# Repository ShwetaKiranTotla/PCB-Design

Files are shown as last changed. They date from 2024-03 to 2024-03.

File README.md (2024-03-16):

# PCB-Design
I had attended a course "Design with KiCAD" (By Wissam Botros) on Udemy from which I learnt the know-hows of PCB Design. This repository contains source files for the open-source projects I have designed along with other finished PCBs I have built.

#
3D model of a Motor Controller board for DC and stepper motors based on the L298 driver module. It can drive two 3-30V DC motors and is capable of 2A continuous current per channel. 
Motor_Controller_3d_board1
 
#
Power Supply module for an Electric Vehicle  
Power_Supply_3d
#
Servo Control Card for an Aerospace application that independently controls six servo motor driven by PWM signals from micrcontroller and receives analog feedback.
Servo_Control_Card 3d
#
Schematic of the L298 Motor Controller Board.
Motor_Controller_Schematic_1

PCB Design of the Motor Controller board
motor_controller_pcb1

Back view of the Motor Controller PCB  
Motor_Controller_3d_board2

#
A three phase level shifter PCB to drive a three phase six signal load from PWM signals generated by micrcontroller.
level_shifter_1

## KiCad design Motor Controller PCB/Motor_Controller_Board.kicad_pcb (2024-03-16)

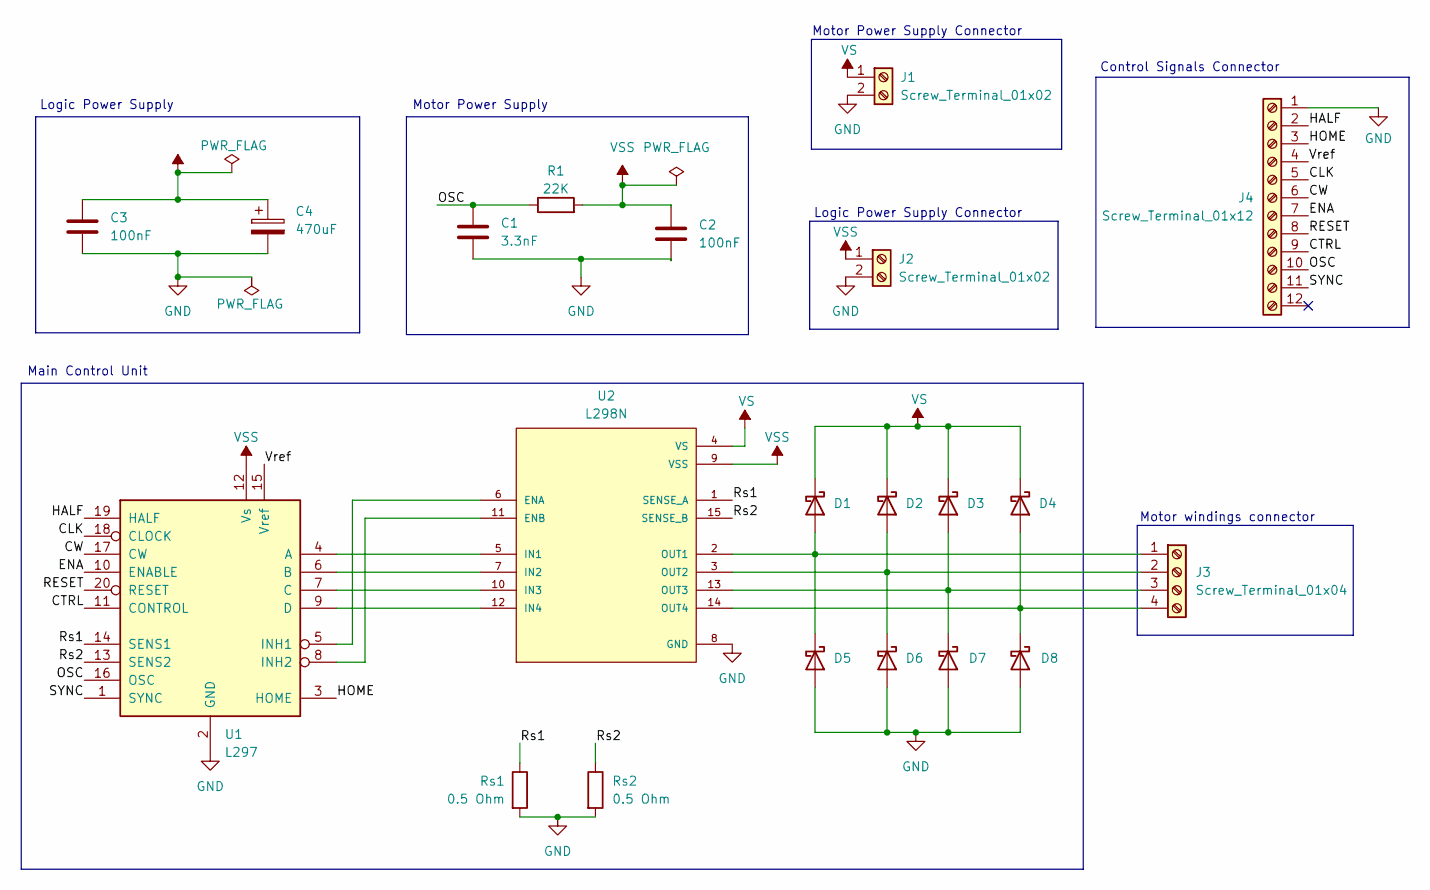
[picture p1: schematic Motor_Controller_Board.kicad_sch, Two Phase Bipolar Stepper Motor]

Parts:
C1: 3.3nF; C_Rect_L10.0mm_W3.0mm_P7.50mm_FKS3_FKP3
C2, C3: 100nF; C_Rect_L7.5mm_W6.5mm_P5.00mm
C4: 470uF; CP_Radial_D13.0mm_P5.00mm
D1, D2, D3, D4, D5, D6, D7, D8: D_Schottky; D_DO-27_P15.24mm_Horizontal
J1, J2: Screw_Terminal_01x02; TerminalBlock_Phoenix_MKDS-1,5-2-5.08_1x02_P5.08mm_Horizont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
J3: Screw_Terminal_01x04; TerminalBlock_Phoenix_MKDS-1,5-4_1x04_P5.00mm_Horizontal
J4: Screw_Terminal_01x12; TerminalBlock_Phoenix_MKDS-1,5-12_1x12_P5.00mm_Horizontal
R1: 22K; R_Axial_DIN0922_L20.0mm_D9.0mm_P25.40mm_Horizontal
Rs1, Rs2: 0.5 Ohm; R_Axial_DIN0414_L11.9mm_D4.5mm_P15.24mm_Horizontal
U1: L297; DIP-20_W7.62mm_LongPads
U2: L298N; TO127P2020X500X2100-15; DigiKey_Part_Number 497-1395-5-ND

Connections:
/CLK: J4.5, U1.18 (CLOCK)
/CTRL: J4.9, U1.11 (CONTROL)
/CW: J4.6, U1.17 (CW)
/ENA: J4.7, U1.10 (ENABLE)
/HALF: J4.2, U1.19 (HALF)
/HOME: J4.3, U1.3 (HOME)
/OSC: C1.1, J4.10, R1.1, U1.16 (OSC)
/RESET: J4.8, U1.20 (RESET)
/Rs1: Rs1.1, U1.14 (SENS1), U2.1 (SENSE_A)
/Rs2: Rs2.1, U1.13 (SENS2), U2.15 (SENSE_B)
/SYNC: J4.11, U1.1 (SYNC)
/Vref: J4.4, U1.15 (Vref)
GND: C1.2, C2.2, C3.2, C4.2, D5.2 (A), D6.2 (A), D7.2 (A), D8.2 (A), J1.2, J2.2, J4.1, Rs1.2, Rs2.2, U1.2 (GND), U2.8 (GND)
unnamed: D1.2 (A), D5.1 (K), J3.1, U2.2 (OUT1)
unnamed: D2.2 (A), D6.1 (K), J3.2, U2.3 (OUT2)
unnamed: D3.2 (A), D7.1 (K), J3.3, U2.13 (OUT3)
unnamed: D4.2 (A), D8.1 (K), J3.4, U2.14 (OUT4)
unnamed: U1.4 (A), U2.5 (IN1)
unnamed: U1.6 (B), U2.7 (IN2)
unnamed: U1.7 (C), U2.10 (IN3)
unnamed: U1.9 (D), U2.12 (IN4)
unnamed: U1.5 (INH1), U2.6 (ENA)
unnamed: U1.8 (INH2), U2.11 (ENB)
VS: C3.1, C4.1, D1.1 (K), D2.1 (K), D3.1 (K), D4.1 (K), J1.1, U2.4 (VS)
VSS: C2.1, J2.1, R1.2, U1.12 (Vs), U2.9 (VSS)

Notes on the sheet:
Logic Power Supply Connector
Main Control Unit
Motor Power Supply Connector
Logic Power Supply
Control Signals Connector
Motor windings connector
Motor Power Supply

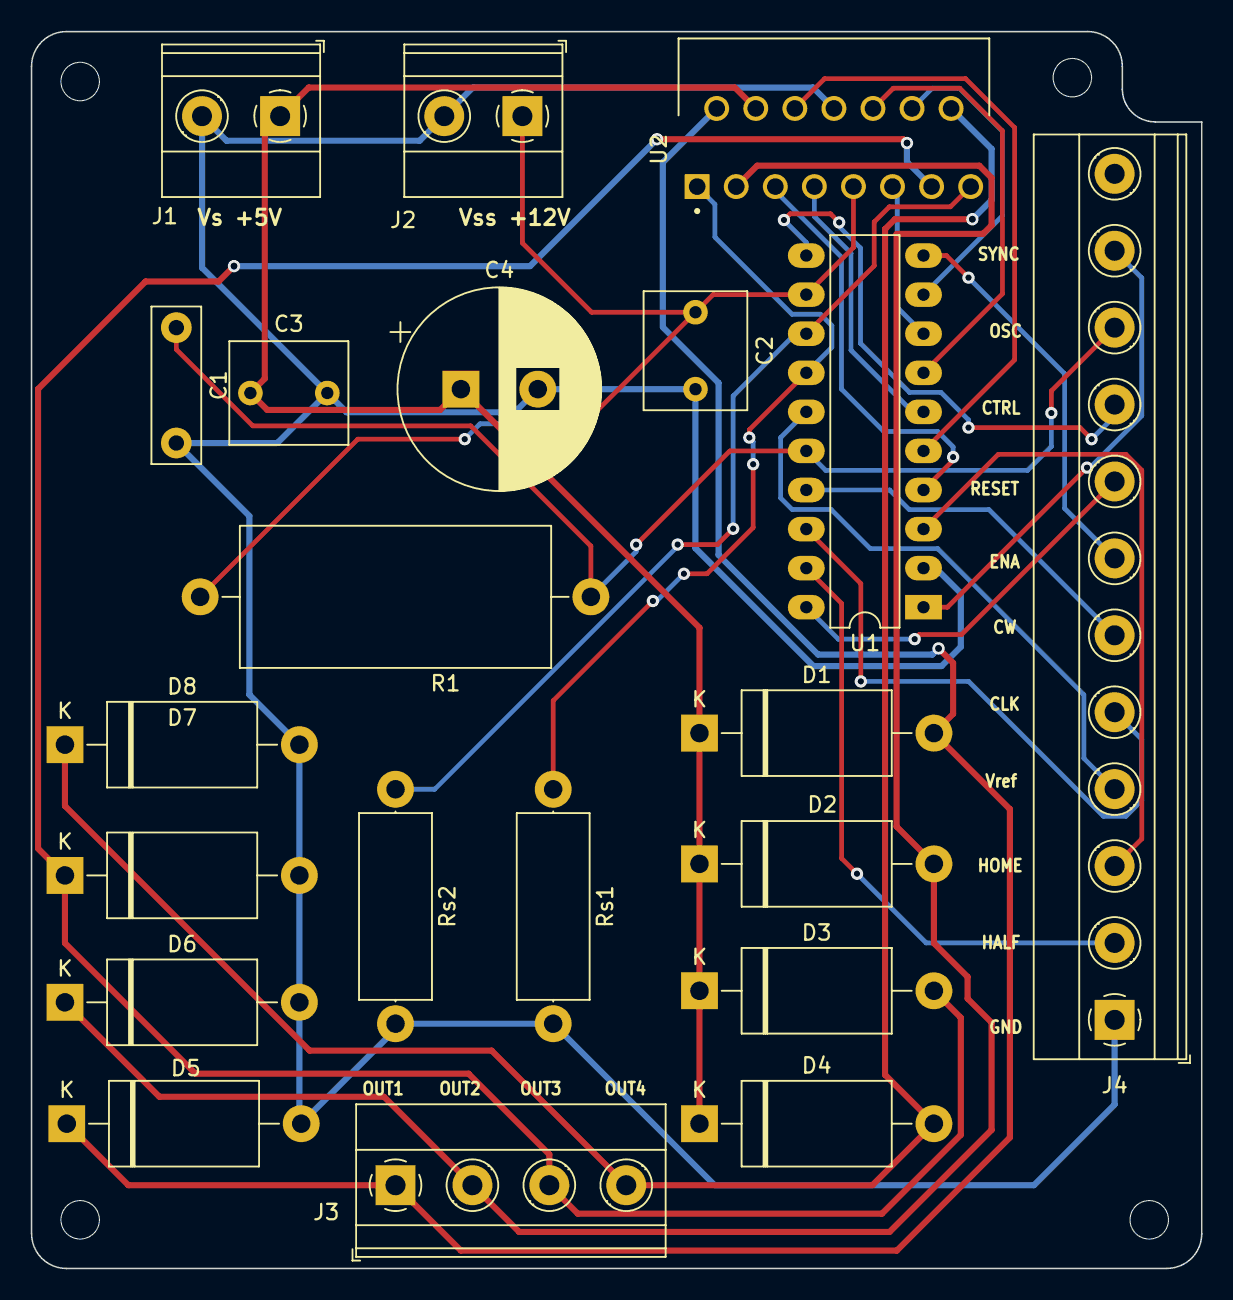
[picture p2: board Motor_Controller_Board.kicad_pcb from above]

Board: 2 copper layers, 76.1 x 80.4 mm, 21 parts (0 on the bottom side), 25 nets.

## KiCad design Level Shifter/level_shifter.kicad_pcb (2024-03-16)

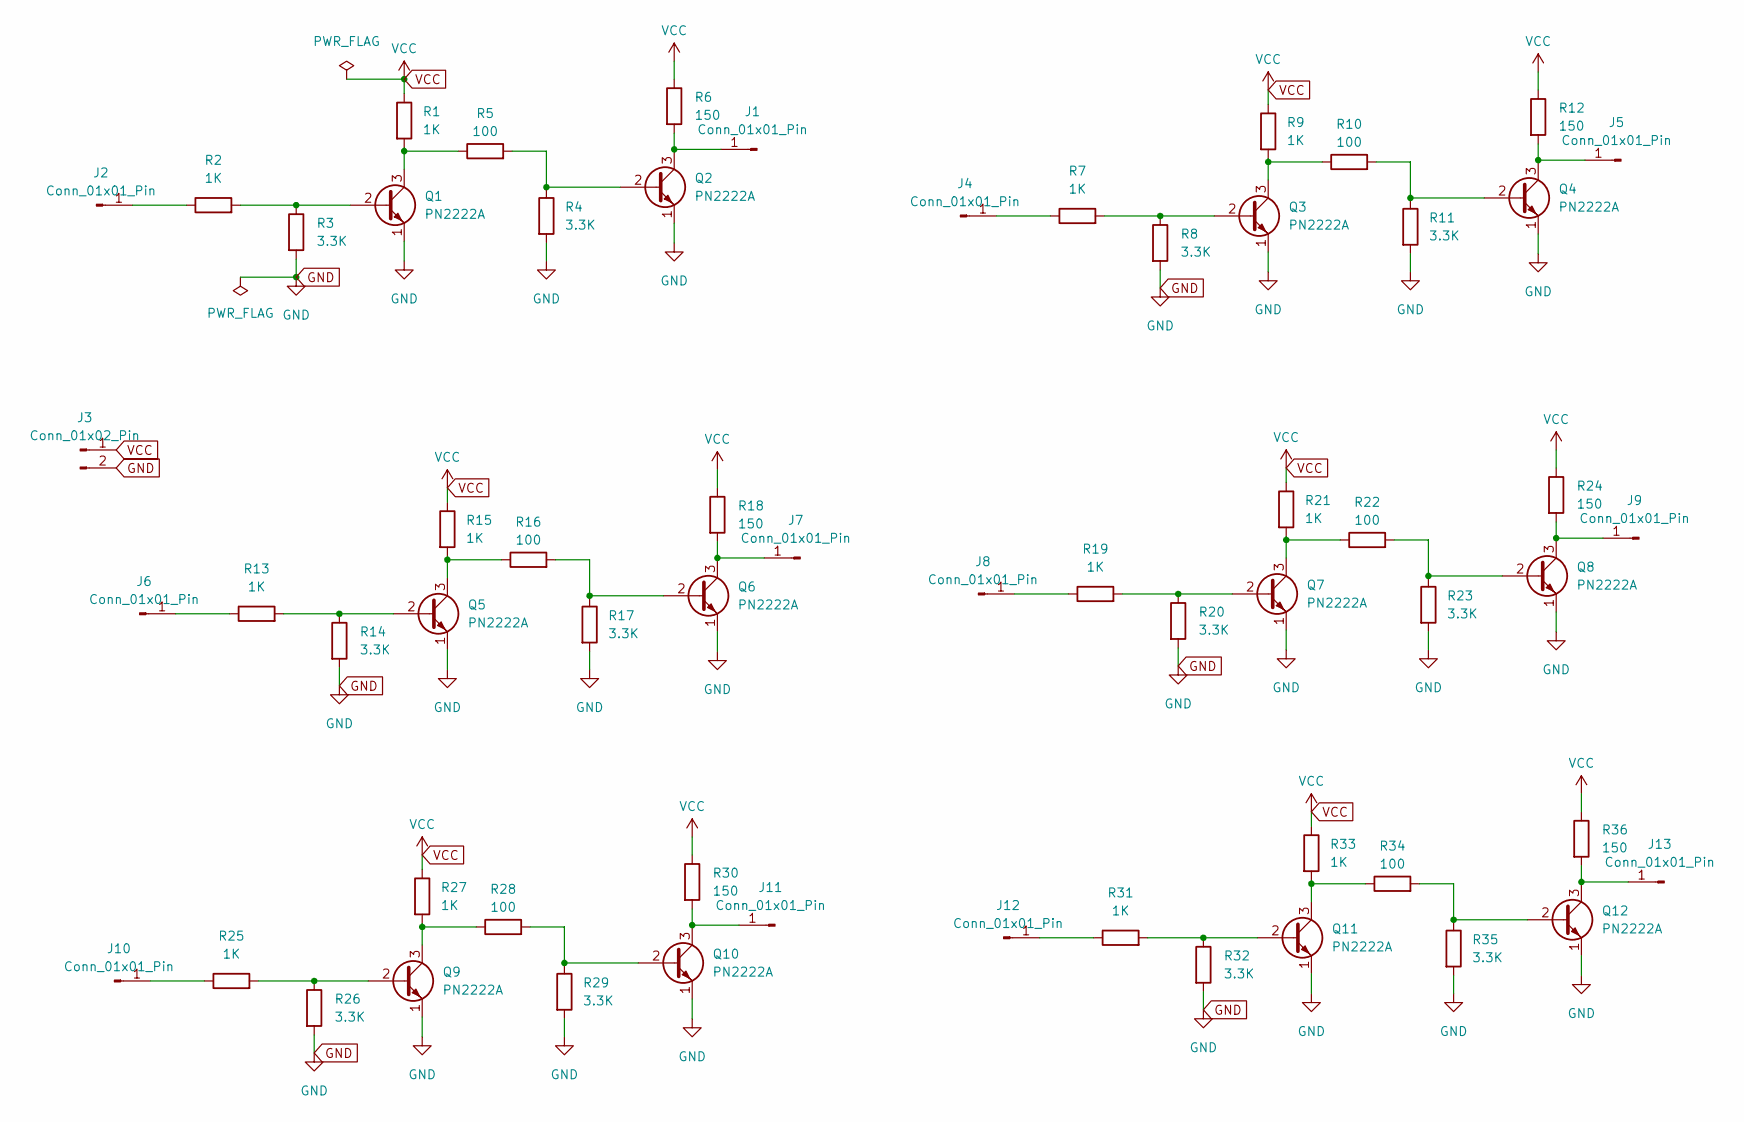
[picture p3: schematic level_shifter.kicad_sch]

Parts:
J1, J2, J4, J5, J6, J7, J8, J9, J10, J11, J12, J13: Conn_01x01_Pin; PinHeader_1x01_P2.54mm_Horizontal
J3: Conn_01x02_Pin; PinHeader_1x02_P2.54mm_Vertical
Q1, Q2, Q3, Q4, Q5, Q6, Q7, Q8, Q9, Q10, Q11, Q12: PN2222A; TO-92_Inline
R1, R2, R7, R9, R13, R15, R19, R21, R25, R27, R31, R33: 1K; R_0603_1608Metric
R3, R4, R8, R11, R14, R17, R20, R23, R26, R29, R32, R35: 3.3K; R_0603_1608Metric
R5, R10, R16, R22, R28, R34: 100; R_0603_1608Metric
R6, R12, R18, R24, R30, R36: 150; R_0603_1608Metric

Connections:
GND: J3.2, Q1.1 (E), Q2.1 (E), Q3.1 (E), Q4.1 (E), Q5.1 (E), Q6.1 (E), Q7.1 (E), Q8.1 (E), Q9.1 (E), Q10.1 (E), Q11.1 (E), Q12.1 (E), R3.2, R4.2, R8.2, R11.2, R14.2, R17.2, R20.2, R23.2, R26.2, R29.2, R32.2, R35.2
unnamed: J1.1, Q2.3 (C), R6.2
unnamed: J2.1, R2.1
unnamed: J4.1, R7.1
unnamed: J5.1, Q4.3 (C), R12.2
unnamed: J6.1, R13.1
unnamed: J7.1, Q6.3 (C), R18.2
unnamed: J8.1, R19.1
unnamed: J9.1, Q8.3 (C), R24.2
unnamed: J10.1, R25.1
unnamed: J11.1, Q10.3 (C), R30.2
unnamed: J12.1, R31.1
unnamed: J13.1, Q12.3 (C), R36.2
unnamed: Q1.2 (B), R2.2, R3.1
unnamed: Q1.3 (C), R1.2, R5.1
unnamed: Q2.2 (B), R4.1, R5.2
unnamed: Q3.2 (B), R7.2, R8.1
unnamed: Q3.3 (C), R9.2, R10.1
unnamed: Q4.2 (B), R10.2, R11.1
unnamed: Q5.2 (B), R13.2, R14.1
unnamed: Q5.3 (C), R15.2, R16.1
unnamed: Q6.2 (B), R16.2, R17.1
unnamed: Q7.2 (B), R19.2, R20.1
unnamed: Q7.3 (C), R21.2, R22.1
unnamed: Q8.2 (B), R22.2, R23.1
unnamed: Q9.2 (B), R25.2, R26.1
unnamed: Q9.3 (C), R27.2, R28.1
unnamed: Q10.2 (B), R28.2, R29.1
unnamed: Q11.2 (B), R31.2, R32.1
unnamed: Q11.3 (C), R33.2, R34.1
unnamed: Q12.2 (B), R34.2, R35.1
VCC: J3.1, R1.1, R6.1, R9.1, R12.1, R15.1, R18.1, R21.1, R24.1, R27.1, R30.1, R33.1, R36.1

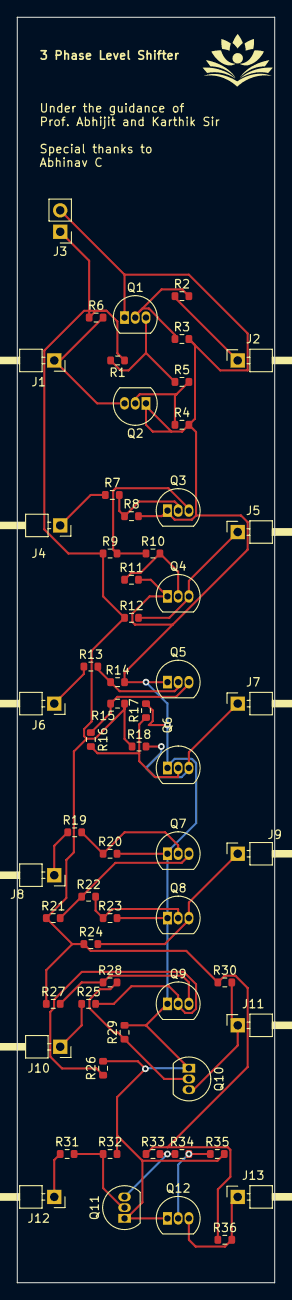
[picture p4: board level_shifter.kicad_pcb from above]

Board: 2 copper layers, 30.5 x 149.9 mm, 61 parts (0 on the bottom side), 32 nets.

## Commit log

2024-03-16 PCB Project Details
2024-03-16 Added PCB Project files.
2024-03-16 Motor Controller PCB
2024-03-16 Added source files
    [Motor_Controller_Board.kicad_pcb, Motor_Controller_Board.kicad_sch]
